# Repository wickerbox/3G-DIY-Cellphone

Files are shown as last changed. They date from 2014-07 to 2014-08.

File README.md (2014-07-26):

cellphone3g
===========

Hardware for a 3G cellphone based on GSM/GPRS Arduino shield and damellis' DIY Cellphone.

[David A Mellis' DIY Cellphone 2G 'Cellphone Module'](http://web.media.mit.edu/~mellis/gsm/)

That project uses the 2G Quectel M10 Module which is pin compatible with the 3G Quectel UC15 Module. 

[Quectel GSM/GPRS M10](http://www.quectel.com/product/prodetail.aspx?id=14)

[Quectel UMTS/HSDPA UC15](http://www.quectel.com/product/prodetail.aspx?id=64)

[Quectel M10 and UC15 Design Compatibility](http://top-electronics.com/news/26/quectel-uc15-and-m10-design-compatibility.html)

**Differences**

1. Slightly different 3.3V-4.3V (UC15) vs 3.3V-4.6V (M10). Using a 3.7V battery is fine. MCP73831 recharges the 3.7V battery from the USB ... if the unit is powered off USB, it's at 4.2V which is on the high end. which is a little too close for comfort so I'd want to replace it with a USIM is the same. 

1. Frequency bands are slightly different but not much.

1. Pinout from controller will have to change. 

**Vocabulary**

GSM - Global System for Mobile Communications, 2G  
GPRS - General Packet Radio Services, packet data service on 2G and 3G  
UMTS - Universal Mobile Telecommunications System, 3G  
HSDPA - High-Speed Downlink Packet Access, allows higher speeds 3G speeds

**Reference**

"GSM (Global System for Mobile Communications, originally Groupe Spécial Mobile), is a standard developed by the European Telecommunications Standards Institute (ETSI) to describe protocols for second generation (2G) digital cellular networks used by mobile phones." [Wikipedia](http://en.wikipedia.org/wiki/GSM)

"General packet radio service (GPRS) is a packet oriented mobile data service on the 2G and 3G cellular communication system's global system for mobile communications (GSM)." [Wikipedia](http://en.wikipedia.org/wiki/General_Packet_Radio_Service)

"UMTS specifies a complete network system, which includes the radio access network (UMTS Terrestrial Radio Access Network, or UTRAN), the core network (Mobile Application Part, or MAP) and the authentication of users via SIM (subscriber identity module) cards." [Wikipedia](http://en.wikipedia.org/wiki/Universal_Mobile_Telecommunications_System)

"High-Speed Downlink Packet Access (HSDPA) is an enhanced 3G (third-generation) mobile-telephony communications protocol in the High-Speed Packet Access (HSPA) family, also dubbed 3.5G, 3G+, or Turbo 3G, which allows networks based on Universal Mobile Telecommunications System (UMTS) to have higher data-transfer speeds and capacity." [Wikipedia](en.wikipedia.org/wiki/High-Speed_Downlink_Packet_Access)

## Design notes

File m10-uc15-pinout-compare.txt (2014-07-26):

PIN   M10           UC15
---   ---           ----
1     SD_DATA       RESERVED
2     SD_CLK        AP_READY
3     SD_CMD        RESERVED
4     RESERVED      RESERVED
5     RESERVED      RESERVED
6     NETLIGHT      NETLIGHT
7     VDD_EXT       VDD_EXT
8     GND           USIM_GND 
9     DBG_RXD       RESERVED
10    DBG_TXD       RESERVED
11    SIM_PRESENCE  USIM_PRESENCE
12    SIM_VDD       USIM_VDD
13    SIM_DATA      USIM_DATA
14    SIM_CLK       USIM_CLK
15    SIM_RST       USIM_RST
16    VRTC          RESERVED
17    EMERG_OFF     RESET_N
18    PWERKEY       PWRKEY
19    AGND          AGND
20    SPK2P         SPK2P
21    SPK1N         SPK1N
22    SPK1P         SPK1P
23    MIC1P         MIC1P
24    MIC1N         MIC1N
25    MIC2P         MIC2P
26    MIC2N         MIC2N
27    RESERVED      RESERVED
28    RESERVED      RESERVED
29    RESERVED      RESERVED
30    RESERVED      RESERVED
31    RESERVED      RESERVED
32    RESERVED      RESERVED
33    RESERVED      RESERVED
34    RESERVED      PCM_DOUT
35    RESERVED      PCM_DIN
36    RESERVED      PCM_CLK
37    RESERVED      PCM_SYNC
38    GPIO1         I2C_SDA
39    RESERVED      I2C_SCL
40    ADC1          ADC1
41    ADC0          ADC0
42    GND           GND
43    RF_ANT        RF_ANT
44    GND           GND
45    GND           GND
46    GND           GND
47    GND           GND
48    GND           GND
49    GND           GND
50    VBAT          VBAT_RF
51    VBAT          VBAT_RF
52    VBAT          VBAT_BB
53    RESERVED      VBAT_BB
54    STATUS        STATUS
55    RI            RI
56    DCD           DCD
57    CTS           CTS
58    RTS           RTS
59    DTR           DTR
60    TXD           TXD
61    RXD           RXD
62    TXD3          USB_DP
63    RXD3          USB_DM
64    GPIO0         USB_VBUS

65                  GND
66                  RESERVED
67                  GND
68                  GND
69-80               RESERVED
81-108              GND

NOTES

1. Keep all RESERVED pins and unused pins unconnected.
2. GND pads 81-108 should be connected to ground. 
3. We need the Telematics version to support the speakers and mic.

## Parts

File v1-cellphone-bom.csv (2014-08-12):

Item | Qty | Refdes | Description | Mfr | Mfr P/N | Digikey P/N | Unit Cost | Total Cost | Notes
1 | 1 | ANT1 | Antenna, Chip, Calvus, 824-960MHZ SMD | Antenova | A10340 | 627-1022-1-ND | $4.78 | $4.78
2 | 11 | C1, C2, C5, C12, C13, C15, C17, C18, C19, C23, C41 | Capacitor, Ceramic, 100nF 16V 5% X7R 0603 | Samsung | CL10B104JO8NNNC | 1276-1061-1-ND | $0.11 | $1.21
3 | 3 | C3, C4, C39 | Capacitor, Ceramic, 4.7uF 16V 10% X7R 0603 | Samsung | CL10A475KO8NNNC | 1276-1784-1-ND | $0.26 | $0.78
4 | 1 | C8 | Capacitor, Ceramic, 3.9pF 100V NP0 0603 | Murata | GQM1885C2A3R9BB01D | 490-4841-1-ND | $0.72 | $0.72
5 | 10 | C6, C7, C9, C24, C27, C28, C29, C33, C34, C35 | Capacitor, Ceramic, 33pF 16V 5% X7R 0603 | AVX | 0603YC330JAT2A | 478-6211-1-ND | $0.12 | $1.20
6 | 1 | C11 | Capacitor, Aluminum, 1000uF 50V 20% Radial | Nichicon | UVR1H102MHD | 493-1111-ND | $0.96 | $0.96
7 | 2 | C10, C14 | Capacitor, Ceramic, 18pF 16V 5% NP0 0603 | Kemet | C0603C180J4GACTU | 399-11141-1-ND | $0.25 | $0.50
8 | 1 | C40 | Capacitor, Ceramic, 10nF 16V 10% X7R 0603 | Samsung | CL10B103KO8NNNC | 1276-1926-1-ND | $0.10 | $0.10
9 | 1 | C26 | Capacitor, Ceramic, 100uF 16V 20% X5R 1210 | Kemet | EMK325ABJ107MM-T | 587-3152-1-ND | $2.30 | $2.30
10 | 8 | C21, C25, C30, C31, C32, C36, C37, C38 | Capacitor, Ceramic, 10pF 50V 5% NP0 0603 | Samsung | CL10C100JB8NCNC | 1276-2154-1-ND | $0.10 | $0.80
11 | 1 | J1 | Connector, AVR ISP, 2x3, Male, R/A, 0.1” | Harwin | M20-8760342 | 952-1922-ND | $0.43 | $0.43
12 | 1 | J2 | Connector, Micro USB-B, SMD with TH Shell | Hirose | ZX62D-B-5P8 | H11610CT-ND | $1.20 | $1.20
13 | 3 | J3,J6,J7 | Connector, Straight, Female, Unshrouded, 4-pin, 0.1” | Sullins | PPPC041LFBN-RC | S7037-ND | $0.60 | $1.80
14 | 1 | J4 | Connector, Straight, Male, Unshrouded, 6-pin, 0.1” | Harwin | M20-9990645 | 952-2269-ND | $0.26 | $0.26
15 | 1 | J5 | Connector, PH Series, Battery, 2-pin, 2MM, SMT | JST | S2B-PH-SM4-TB(LF)(SN) | 455-1749-1-ND | $0.56 | $0.56
16 | 1 | L1 | Inductor, 6.8nH 430mA 0603 | Murata | LQG18HN6N8J00D | 490-1108-1-ND | $0.21 | $0.21
17 | 1 | L2 | Inductor, 3.3nH 500mA 0603 | Murata | LQG18HN3N3S00D | 490-1104-1-ND | $0.21 | $0.21
18 | 5 | LED1, LED2, LED3, LED4, LED5 | LED, Chip, Pure Green, SMD, 0603 | Stanley | BG1111C-TR | 404-1005-1-ND | $0.57 | $2.85
19 | 1 | Q1 | Mic, Electret, Conditioned Analog Omni -44dB | CUI | CMA-4544PF-W | 102-1721-ND | $0.96 | $0.96
20 | 2 | Q2, Q3 | MOSFET, N-CH, 20V 3.2A SOT-23 | ON Semi | NTR4501NT1G | NTR4501NT1GOSCT-ND | $0.59 | $1.18
21 | 3 | R2, R3, R6 | Resistor, 22 OHM 1/4W 5% 0603 | Rohm | ESR03EZPJ220 | RHM22DCT-ND | $0.10 | $0.30
22 | 5 | R1, R5, R7, R9, R10 | Resistor, 470 OHM 1/4W 5% 0603 | Rohm | ESR03EZPJ471 | RHM470DCT-ND | $0.10 | $0.50
23 | 2 | R11, R12 | Resistor, 4.99K 1/8W 1% 0603 | Stackpole | RNCP0603FTD4K99 | RNCP0603FTD4K99CT-ND | $0.05 | $0.10
24 | 1 | R8 | Resistor, 2K 1/8W 1% 0603 | Stackpole | RNCP0603FTD2K00 | RNCP0603FTD2K00CT-ND | $0.05 | $0.05
25 | 1 | R14 | Resistor, 0 OHM 1/8W JUMP 0603 | Vishay | MCT06030Z0000ZP500 | MCT0603-0.0-ZZCT-ND | $0.13 | $0.13
26 | 2 | R4, R13 | Resistor, 10K 1/8W 1% 0603 | Stackpole | RNCP0603FTD10K0 | RNCP0603FTD10K0CT-ND | $0.05 | $0.10
27 | 1 | S1 | Button, Tactile Switch, SPST-NO 0.05A 12V | Omron | B3U-1000P | SW1020CT-ND | $1.25 | $1.25
28 | 1 | SP1 | Speaker, Receiver, 100Hz-9.5kHz 55.5ohm | Knowles | SR6438NWS-000 | 423-1142-ND | $6.27 | $6.27
29 | 1 | U1 | IC, Battery Charge Controller, LiPo, 4.2V, 20T23-5 | Microchip | MCP73831T-2ACI/OT | MCP73831T-2ACI/OTCT-ND | $0.67 | $0.67
30 | 1 | U2 | IC, Microcontroller, 8-bit 128KB FLASH 44TQFP | Atmel | ATMEGA1284P-AUR | ATMEGA1284P-AURCT-ND | $8.99 | $8.99
31 | 1 | U3 | GSM Module, UC15 3G | Quectel | UC15 | SEE NOTE | $65.00 | $65.00 | Order through D'Art Perfect (http://www.d-art-perfect.com/#!product/prd1/1837100545/uc15)
32 | 1 | U4 | IC, Volt Level Translator, 14TSSOP | TI | TXB0104PWR | 296-21929-1-ND | $1.69 | $1.69
33 | 1 | X1 | Connector, SMA Jack, R/A, 50ohm TH | Emerson | 142-0701-301 | J501-ND | $7.76 | $7.76
34 | 1 | X2 | Crystal, 8MHz, 18pF SMD | Abracon | ABM3-8.000MHZ-D2Y-T | 535-10630-1-ND | $1.09 | $1.09
35 | 1 | X3 | Connector, Smart Card (SIM), Hinged, 6-pin SMD | C&K | C707 10M006 5002 | 361-1020-1-ND | $1.03 | $1.03
 |  |  |  |  |  |  | SUM | $117.94 | Total cost with cell module
 |  |  |  |  |  |  | SUM-CELL | $52.94 | Total cost without cell module

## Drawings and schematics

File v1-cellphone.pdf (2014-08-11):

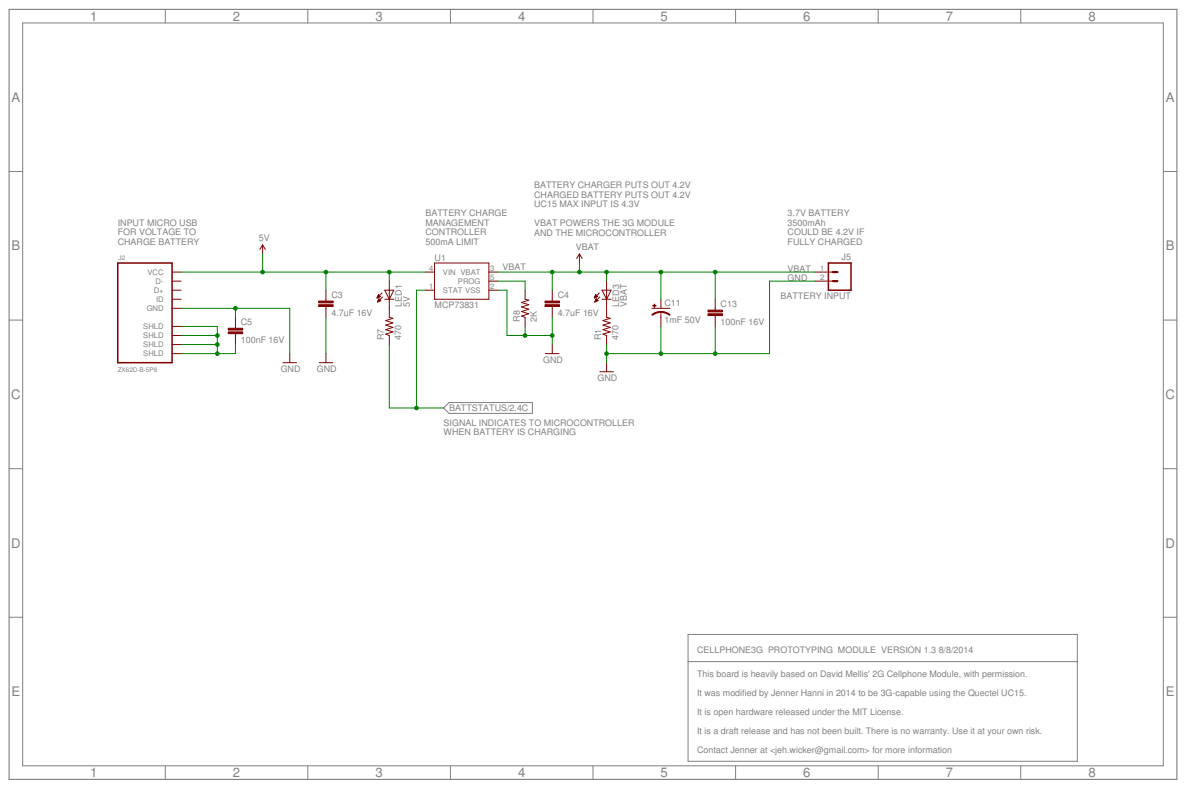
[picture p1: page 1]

BATTERY CHARGER PUTS OUT 4.2V
CHARGED BATTERY PUTS OUT 4.2V
UC15 MAX INPUT IS 4.3V
VBAT POWERS THE 3G MODULE
AND THE MICROCONTROLLER

BATTSTATUS/2.4C
SIGNAL INDICATES TO MICROCONTROLLER
WHEN BATTERY IS CHARGING

This board is heavily based on David Mellis' 2G Cellphone Module, with permission.
It was modified by Jenner Hanni in 2014 to be 3G-capable using the Quectel UC15.
It is open hardware released under the MIT License.
It is a draft release and has not been built. There is no warranty. Use it at your own risk. Contact Jenner at <jeh.wicker@gmail.com> for more information

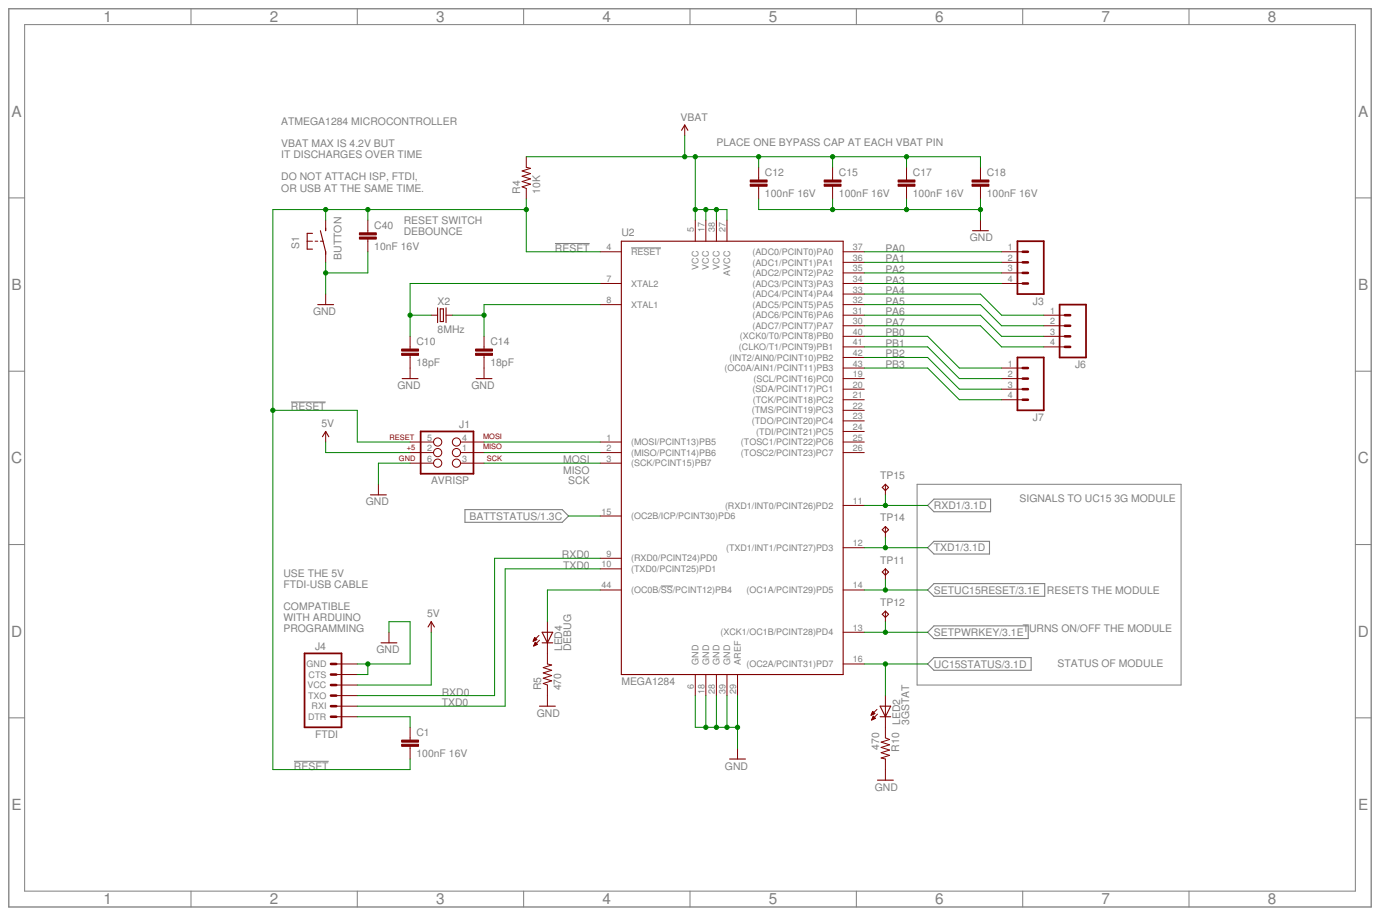
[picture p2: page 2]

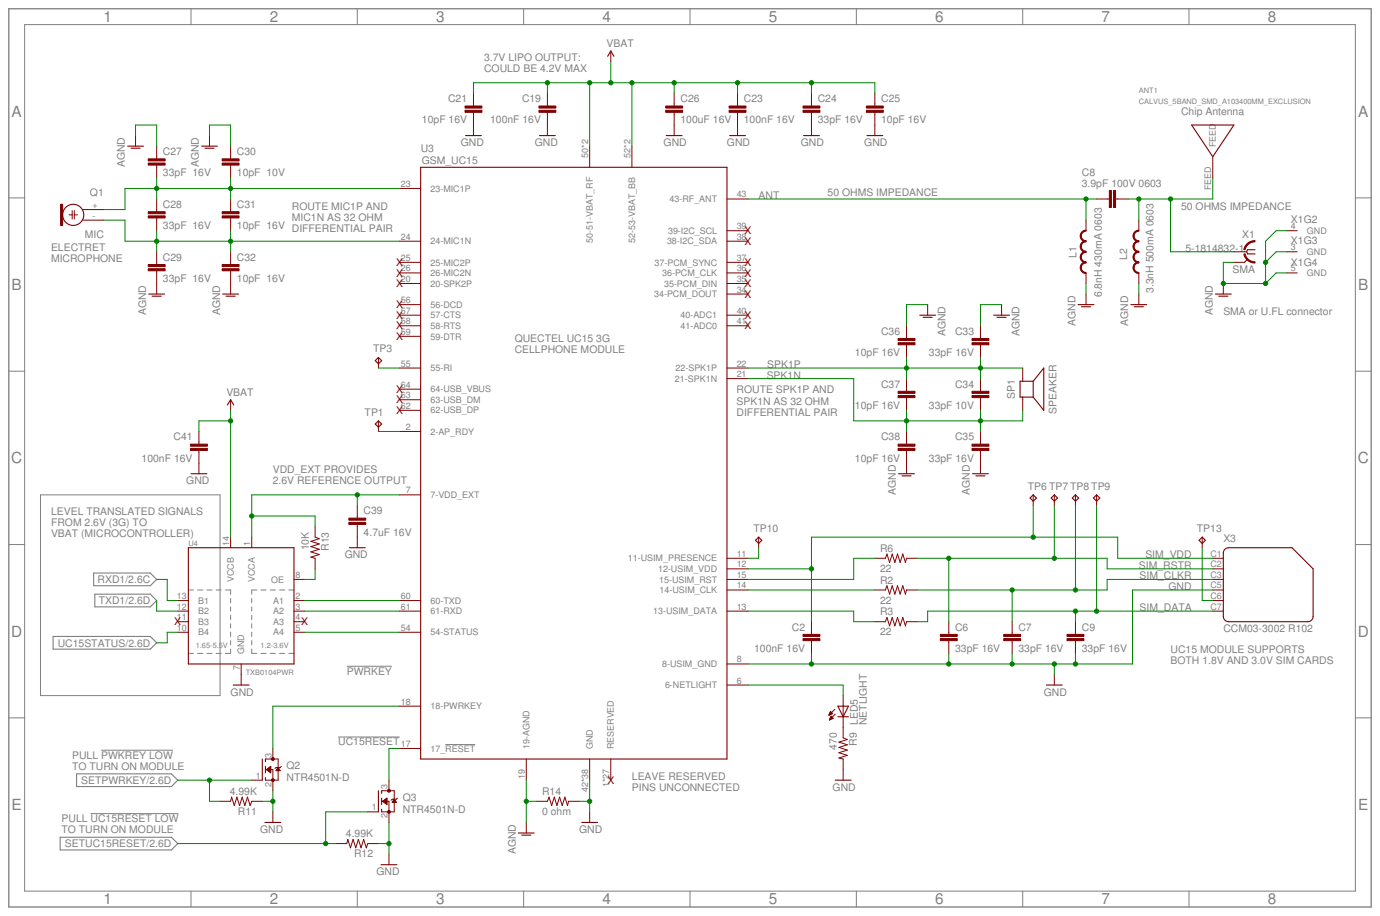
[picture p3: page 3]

VBAT

SMA or U.FL connector

UC15 MODULE SUPPORTS
BOTH 1.8V AND 3.0V SIM CARDS

PULL PWKREY LOW
TO TURN ON MODULE
SETPWRKEY/2.6D

PULL UC15RESET LOW
SETUC15RESET/2.6D

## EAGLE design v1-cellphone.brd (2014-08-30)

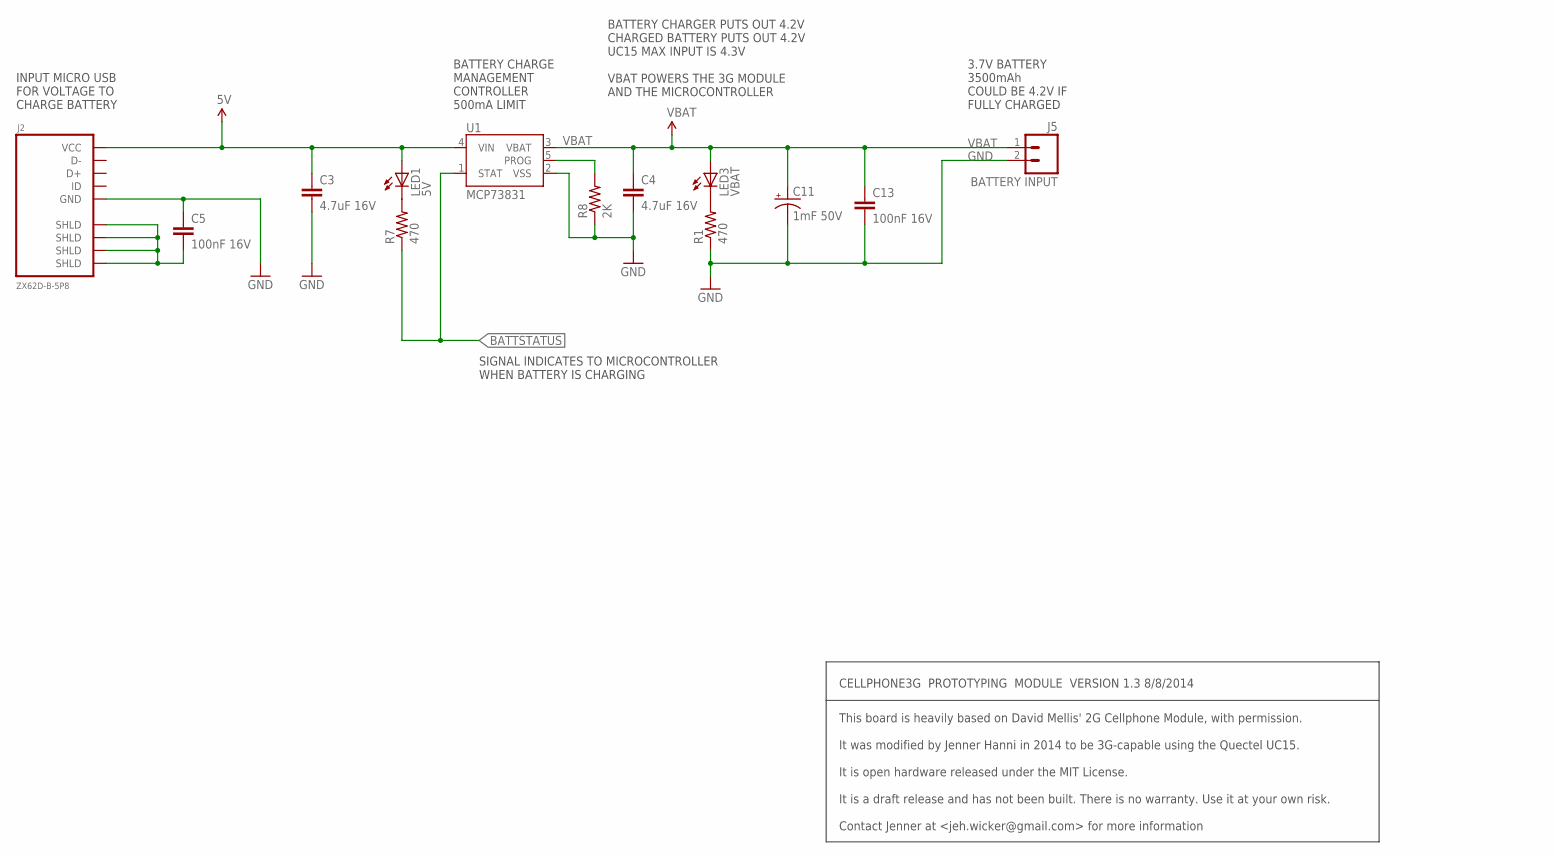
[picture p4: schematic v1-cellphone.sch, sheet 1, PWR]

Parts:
C3, C4: 4.7uF 16V; 0603-B
C5, C13: 100nF 16V; 0603-B
C11: 1mF 50V; CPOL-RADIAL-1000UF-25V
J2: ZX62D-B-5P8
J5: BATTERY INPUT; JST-2-SMD
LED1: 5V; CHIP-LED0603
LED3: VBAT; CHIP-LED0603
R1, R7: 470; 0603-B
R8: 2K; 0603-B
U1: MCP73831; SPARKFUN_SOT23-5

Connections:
5V: C3.1, J2.P1 (VCC), LED1.A, U1.4 (VIN); also elsewhere on the board
BATTSTATUS: R7.1, U1.1 (STAT); also elsewhere on the board
GND: C3.2, C4.2, C5.1, C11.2 (-), C13.2, J2.P5 (GND), J5.2 (1), R1.1, R8.1, U1.2 (VSS); also elsewhere on the board
unnamed: LED3.C, R1.2
unnamed: LED1.C, R7.2
PROG: R8.2, U1.5 (PROG)
SHLD: C5.2, J2.P$1 (SHLD), J2.P$2 (SHLD), J2.P$3 (SHLD), J2.P$4 (SHLD)
VBAT: C4.1, C11.1 (+), C13.1, J5.1 (2), LED3.A, U1.3 (VBAT); also elsewhere on the board

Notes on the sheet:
INPUT MICRO USB FOR VOLTAGE TO CHARGE BATTERY
BATTERY CHARGE MANAGEMENT CONTROLLER 500mA LIMIT
3.7V BATTERY 3500mAh COULD BE 4.2V IF FULLY CHARGED
BATTERY CHARGER PUTS OUT 4.2V CHARGED BATTERY PUTS OUT 4.2V UC15 MAX INPUT IS 4.3V VBAT POWERS THE 3G MODULE AND THE MICROCONTROLLER
CELLPHONE3G PROTOTYPING MODULE VERSION 1.3 8/8/2014
This board is heavily based on David Mellis' 2G Cellphone Module, with permission. It was modified by Jenner Hanni in 2014 to be 3G-capable using the Quectel UC15. It is open hardware released under the MIT License. It is a draft release and has not been built. There is no warranty. Use it at your 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
SIGNAL INDICATES TO MICROCONTROLLER WHEN BATTERY IS CHARGING

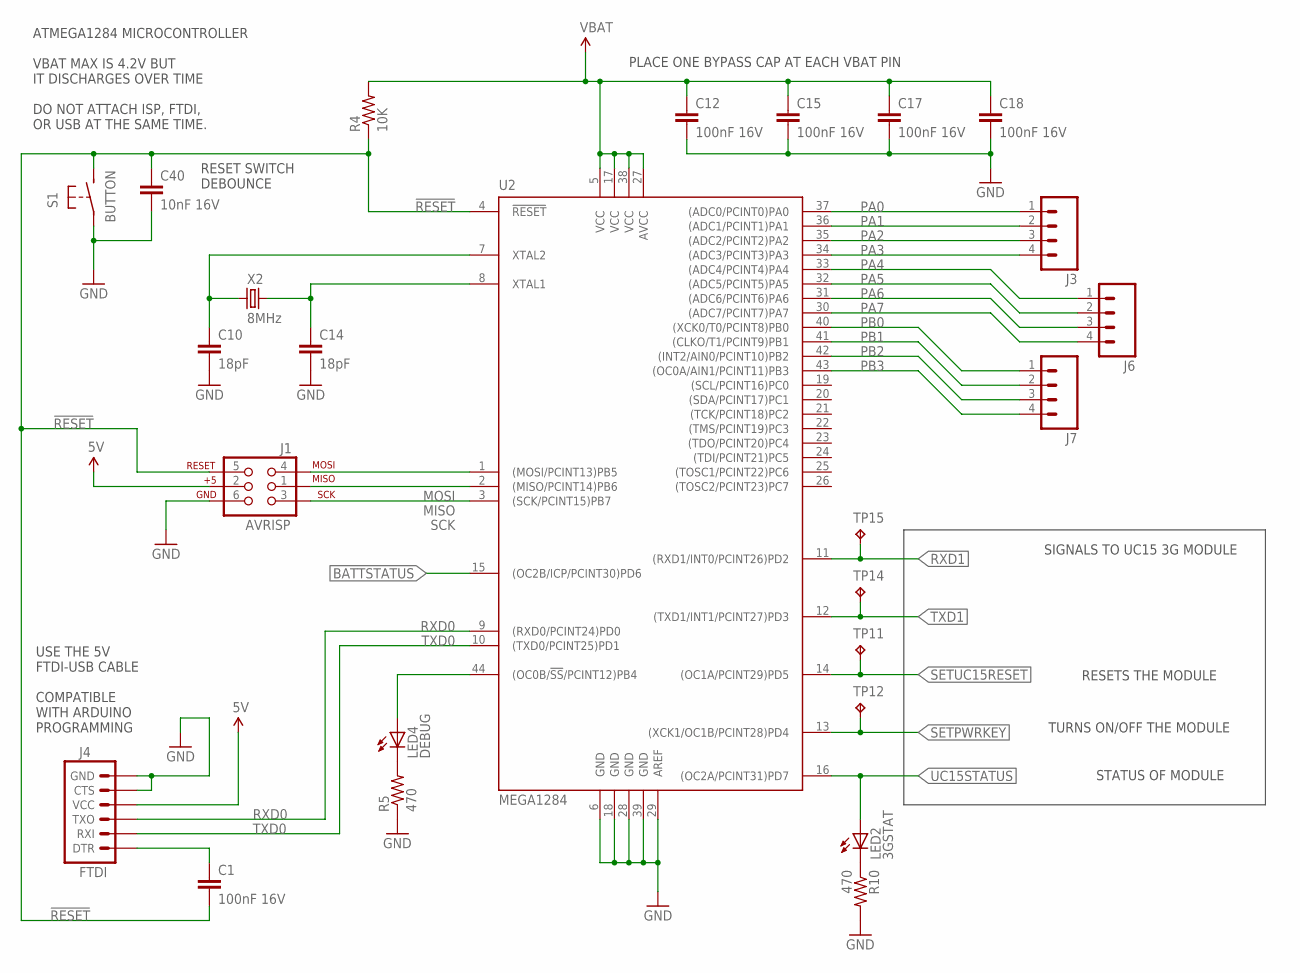
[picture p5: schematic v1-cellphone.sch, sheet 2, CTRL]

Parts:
C1, C12, C15, C17, C18: 100nF 16V; 0603-B
C10, C14: 18pF; 0603-B
C40: 10nF 16V; 0603-B
J1: AVRISP; SPARKFUN-CONNECTORS_2X3-NS
J3, J6, J7: M04LOCK; 1X04_LOCK
J4: FTDI; 1X06_LOCK
LED2: 3GSTAT; CHIP-LED0603
LED4: DEBUG; CHIP-LED0603
R4: 10K; 0603-B
R5, R10: 470; 0603-B
S1: BUTTON; CELLPHONE_B3U-1000P
TP11, TP12, TP14, TP15: TPPAD1-13; P1-13
U2: MEGA1284; AVR-5_TQFP44
X2: 8MHz; 2-SMD-5X3MM

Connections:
5V: J1.2 (2-5VCC), J4.4 (VCC); also elsewhere on the board
!RESET: C1.2, C40.1, J1.5 (5-RESET), R4.1, S1.P$2 (S), U2.4 (!RESET)
BATTSTATUS: U2.15 ((OC2B/ICP/PCINT30)PD6); also elsewhere on the board
DEBUGLED: LED4.A, U2.44 ((OC0B/!SS!/PCINT12)PB4)
GND: C10.2, C12.2, C14.2, C15.2, C17.2, C18.2, C40.2, J1.6 (6-GND), J4.5 (CTS), J4.6 (GND), R5.1, R10.2, S1.P$1, U2.6 (GND), U2.18 (GND), U2.28 (GND), U2.29 (AREF), U2.39 (GND); also elsewhere on the board
MISO: J1.1 (1-MISO), U2.2 ((MISO/PCINT14)PB6)
MOSI: J1.4 (4-MOSI), U2.1 ((MOSI/PCINT13)PB5)
unnamed: LED4.C, R5.2
unnamed: C1.1, J4.1 (DTR)
unnamed: LED2.C, R10.1
PA0: J3.1, U2.37 ((ADC0/PCINT0)PA0)
PA1: J3.2, U2.36 ((ADC1/PCINT1)PA1)
PA2: J3.3, U2.35 ((ADC2/PCINT2)PA2)
PA3: J3.4, U2.34 ((ADC3/PCINT3)PA3)
PA4: J6.1, U2.33 ((ADC4/PCINT4)PA4)
PA5: J6.2, U2.32 ((ADC5/PCINT5)PA5)
PA6: J6.3, U2.31 ((ADC6/PCINT6)PA6)
PA7: J6.4, U2.30 ((ADC7/PCINT7)PA7)
PB0: J7.1, U2.40 ((XCK0/T0/PCINT8)PB0)
PB1: J7.2, U2.41 ((CLKO/T1/PCINT9)PB1)
PB2: J7.3, U2.42 ((INT2/AIN0/PCINT10)PB2)
PB3: J7.4, U2.43 ((OC0A/AIN1/PCINT11)PB3)
RXD0: J4.3 (TXO), U2.9 ((RXD0/PCINT24)PD0)
RXD1: TP15.TP, U2.11 ((RXD1/INT0/PCINT26)PD2); also elsewhere on the board
SCK: J1.3 (3-SCK), U2.3 ((SCK/PCINT15)PB7)
SETPWRKEY: TP12.TP, U2.13 ((XCK1/OC1B/PCINT28)PD4); also elsewhere on the board
SETUC15RESET: TP11.TP, U2.14 ((OC1A/PCINT29)PD5); also elsewhere on the board
TXD0: J4.2 (RXI), U2.10 ((TXD0/PCINT25)PD1)
TXD1: TP14.TP, U2.12 ((TXD1/INT1/PCINT27)PD3); also elsewhere on the board
UC15STATUS: LED2.A, U2.16 ((OC2A/PCINT31)PD7); also elsewhere on the board
VBAT: C12.1, C15.1, C17.1, C18.1, R4.2, U2.5 (VCC), U2.17 (VCC), U2.27 (AVCC), U2.38 (VCC); also elsewhere on the board
XTAL1: C14.1, U2.8 (XTAL1), X2.P$2 (2)
XTAL2: C10.1, U2.7 (XTAL2), X2.P$1 (1)

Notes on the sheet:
PLACE ONE BYPASS CAP AT EACH VBAT PIN
USE THE 5V FTDI-USB CABLE COMPATIBLE WITH ARDUINO PROGRAMMING
TURNS ON/OFF THE MODULE
RESETS THE MODULE
STATUS OF MODULE
SIGNALS TO UC15 3G MODULE
ATMEGA1284 MICROCONTROLLER VBAT MAX IS 4.2V BUT IT DISCHARGES OVER TIME DO NOT ATTACH ISP, FTDI, OR USB AT THE SAME TIME.
RESET SWITCH DEBOUNCE

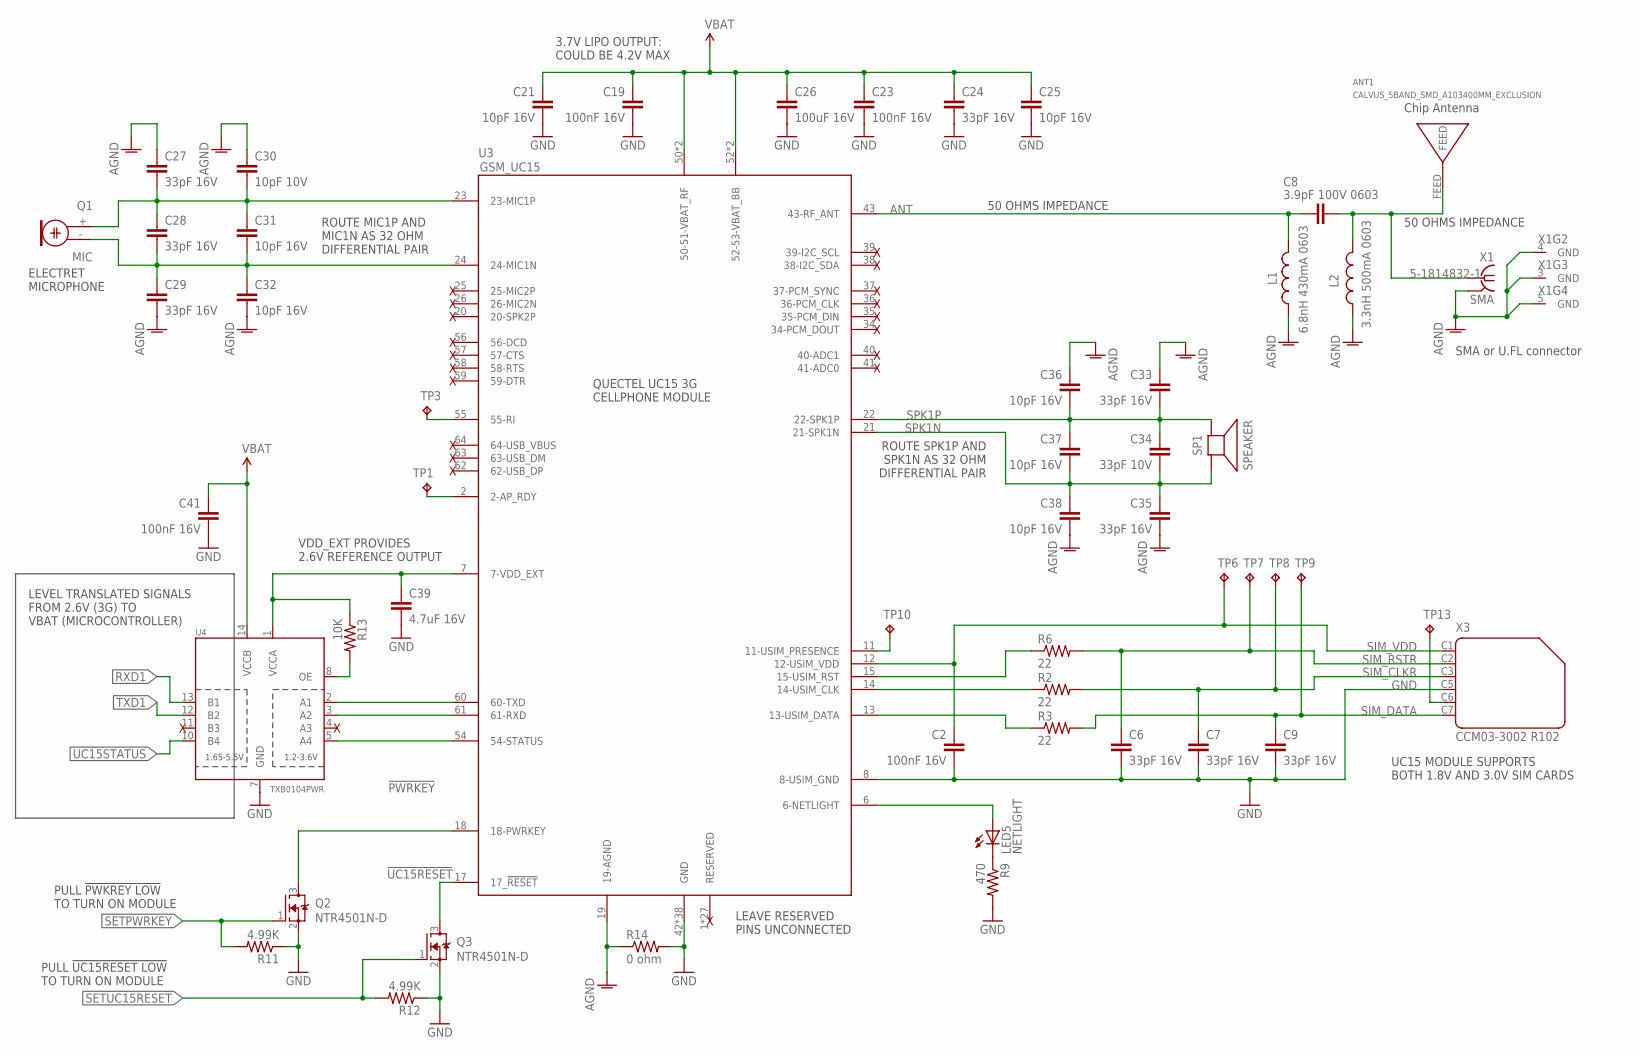
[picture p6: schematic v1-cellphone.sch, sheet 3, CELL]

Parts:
ANT1: CALVUS_5BAND_SMD_A103400MM_EXCLUSION; CALVUS_5BAND_SMD_A10340_0MM_EXCLUSION
C2, C19, C23, C41: 100nF 16V; 0603-B
C6, C7, C9, C24, C27, C28, C29, C33, C35: 33pF 16V; 0603-B
C8: 3.9pF 100V 0603; 0603-B
C21, C25, C31, C32, C36, C37, C38: 10pF 16V; 0603-B
C26: 100uF 16V; C1210K
C30: 10pF 10V; 0603-B
C34: 33pF 10V; 0603-B
C39: 4.7uF 16V; 0603-B
L1: 6.8nH 430mA 0603; 0603-B
L2: 3.3nH 500mA 0603; 0603-B
LED5: NETLIGHT; CHIP-LED0603
Q1: MIC; 9.7ELECTRET
Q2, Q3: NTR4501N-D; SOT-23
R2, R3, R6: 22; 0603-B
R9: 470; 0603-B
R11, R12: 4.99K; 0603-B
R13: 10K; 0603-B
R14: 0 ohm; 0603-B
SP1: SPEAKER; CELLPHONE_SPEAKER-6.4MM
TP1, TP3, TP6, TP7, TP8, TP9, TP10, TP13: TPPAD1-13; P1-13
U3: GSM_UC15; GSM_UC15_WITHOUT_EXCLUSION
U4: TXB0104PWR; TSSOP14
X1: SMA; CON-COAX_BU-SMA-V
X3: CCM03-3002 R102; SMARTPRJ_CON-AMPHENOL_C707_10M006_512_2

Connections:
!PWRKEY: Q2.3 (D), U3.18 (18-PWRKEY)
!UC15RESET: Q3.3 (D), U3.17 (17_!RESET)
AGND: C27.1, C29.2, C30.1, C32.2, C33.1, C35.2, C36.1, C38.2, L1.1, L2.1, R14.1, U3.19 (19-AGND), X1.2 (GND), X1.3 (GND), X1.4 (GND), X1.5 (GND)
ANT: C8.1, L1.2, U3.43 (43-RF_ANT)
ANTENNA: ANT1.FEED, C8.2, L2.2, X1.1
GND: C2.2, C6.2, C7.2, C9.2, C19.2, C21.2, C23.2, C24.2, C25.2, C26.2, C39.2, C41.2, Q2.2 (S), Q3.2 (S), R9.2, R11.1, R12.1, R14.2, U3.8 (8-USIM_GND), U3.42 (GND), U3.44 (GND), U3.45 (GND), U3.46 (GND), U3.47 (GND), U3.48 (GND), U3.49 (GND), U3.65 (GND), U3.67 (GND), U3.68 (GND), U3.81 (GND), U3.82 (GND), U3.83 (GND), U3.84 (GND), U3.85 (GND), U3.86 (GND), U3.87 (GND), U3.88 (GND), U3.89 (GND), U3.90 (GND), U3.91 (GND), U3.92 (GND), U3.93 (GND), U3.94 (GND), U3.95 (GND), U3.96 (GND), U3.97 (GND), U3.98 (GND), U3.99 (GND), U3.100 (GND), U3.101 (GND), U3.102 (GND), U3.103 (GND), U3.104 (GND), U3.105 (GND), U3.106 (GND), U3.107 (GND), U3.108 (GND), U4.7 (GND), X3.C5 (4); also elsewhere on the board
MIC1N: C28.2, C29.1, C31.2, C32.1, Q1.- (1), U3.24 (24-MIC1N)
MIC1P: C27.2, C28.1, C30.2, C31.1, Q1.+ (2), U3.23 (23-MIC1P)
unnamed: R3.1, U3.13 (13-USIM_DATA)
unnamed: LED5.C, R9.1
unnamed: TP13.TP, X3.C6 (5)
unnamed: TP1.TP, U3.2 (2-AP_RDY)
unnamed: TP3.TP, U3.55 (55-RI)
unnamed: U3.60 (60-TXD), U4.2 (A1)
unnamed: U3.61 (61-RXD), U4.3 (A2)
unnamed: U3.54 (54-STATUS), U4.5 (A4)
NETLIGHT: LED5.A, U3.6 (6-NETLIGHT)
OE: R13.2, U4.8 (OE)
PRESENCE: TP10.TP, U3.11 (11-USIM_PRESENCE)
RXD1: U4.13 (B1); also elsewhere on the board
SETPWRKEY: Q2.1 (G), R11.2; also elsewhere on the board
SETUC15RESET: Q3.1 (G), R12.2; also elsewhere on the board
SIM_CLK: R2.1, U3.14 (14-USIM_CLK)
SIM_CLKR: C7.1, R2.2, TP8.TP, X3.C3 (3)
SIM_DATA: C9.1, R3.2, TP9.TP, X3.C7 (6)
SIM_RST: R6.1, U3.15 (15-USIM_RST)
SIM_RSTR: C6.1, R6.2, TP7.TP, X3.C2 (2)
SIM_VDD: C2.1, TP6.TP, U3.12 (12-USIM_VDD), X3.C1 (1)
SPK1N: C34.2, C35.1, C37.2, C38.1, SP1.NEG, U3.21 (21-SPK1N)
SPK1P: C33.2, C34.1, C36.2, C37.1, SP1.POS, U3.22 (22-SPK1P)
TXD1: U4.12 (B2); also elsewhere on the board
UC15STATUS: U4.10 (B4); also elsewhere on the board
VBAT: C19.1, C21.1, C23.1, C24.1, C25.1, C26.1, C41.1, U3.50 (50-51-VBAT_RF), U3.51 (50-51-VBAT_RF), U3.52 (52-53-VBAT_BB), U3.53 (52-53-VBAT_BB), U4.14 (VCCB); also elsewhere on the board
VDD_EXT: C39.1, R13.1, U3.7 (7-VDD_EXT), U4.1 (VCCA)

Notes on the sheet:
Chip Antenna
SMA or U.FL connector
UC15 MODULE SUPPORTS BOTH 1.8V AND 3.0V SIM CARDS
LEAVE RESERVED PINS UNCONNECTED
QUECTEL UC15 3G CELLPHONE MODULE
ELECTRET MICROPHONE
ROUTE MIC1P AND MIC1N AS 32 OHM DIFFERENTIAL PAIR
ROUTE SPK1P AND SPK1N AS 32 OHM DIFFERENTIAL PAIR
50 OHMS IMPEDANCE
3.7V LIPO OUTPUT: COULD BE 4.2V MAX
LEVEL TRANSLATED SIGNALS FROM 2.6V (3G) TO VBAT (MICROCONTROLLER)
PULL !PWKREY LOW TO TURN ON MODULE
PULL !UC15RESET LOW TO TURN ON MODULE
VDD_EXT PROVIDES 2.6V REFERENCE OUTPUT

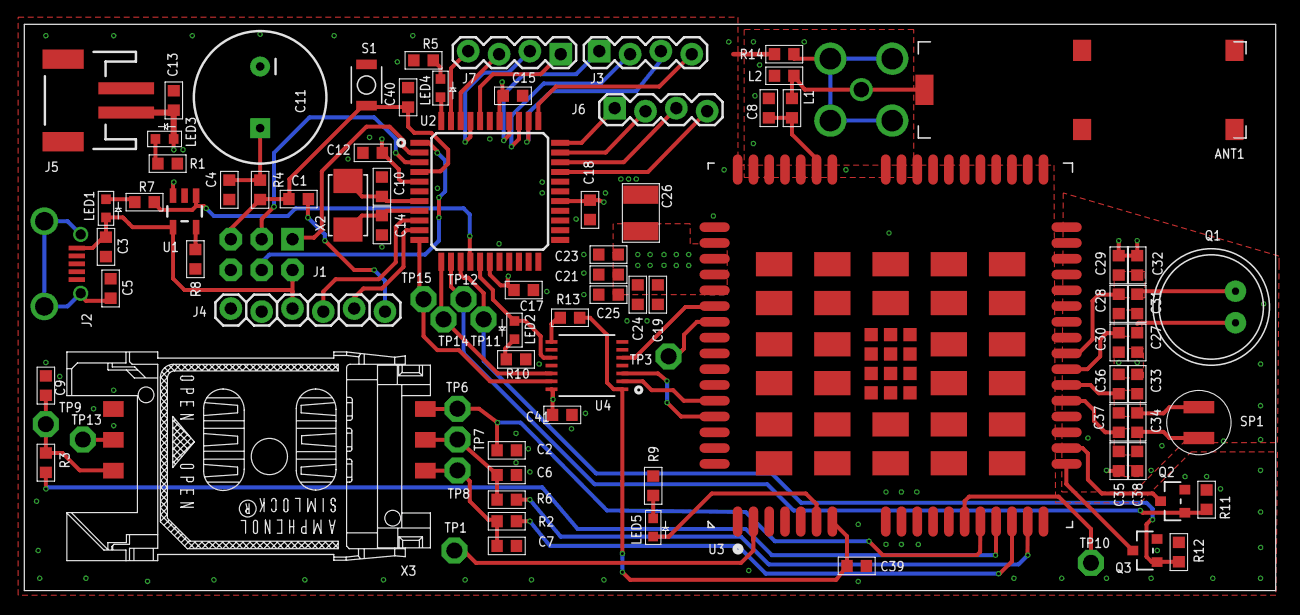
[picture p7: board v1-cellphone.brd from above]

Board: 4 copper layers, 103.1 x 46.7 mm, 91 parts (1 on the bottom side), 64 nets.

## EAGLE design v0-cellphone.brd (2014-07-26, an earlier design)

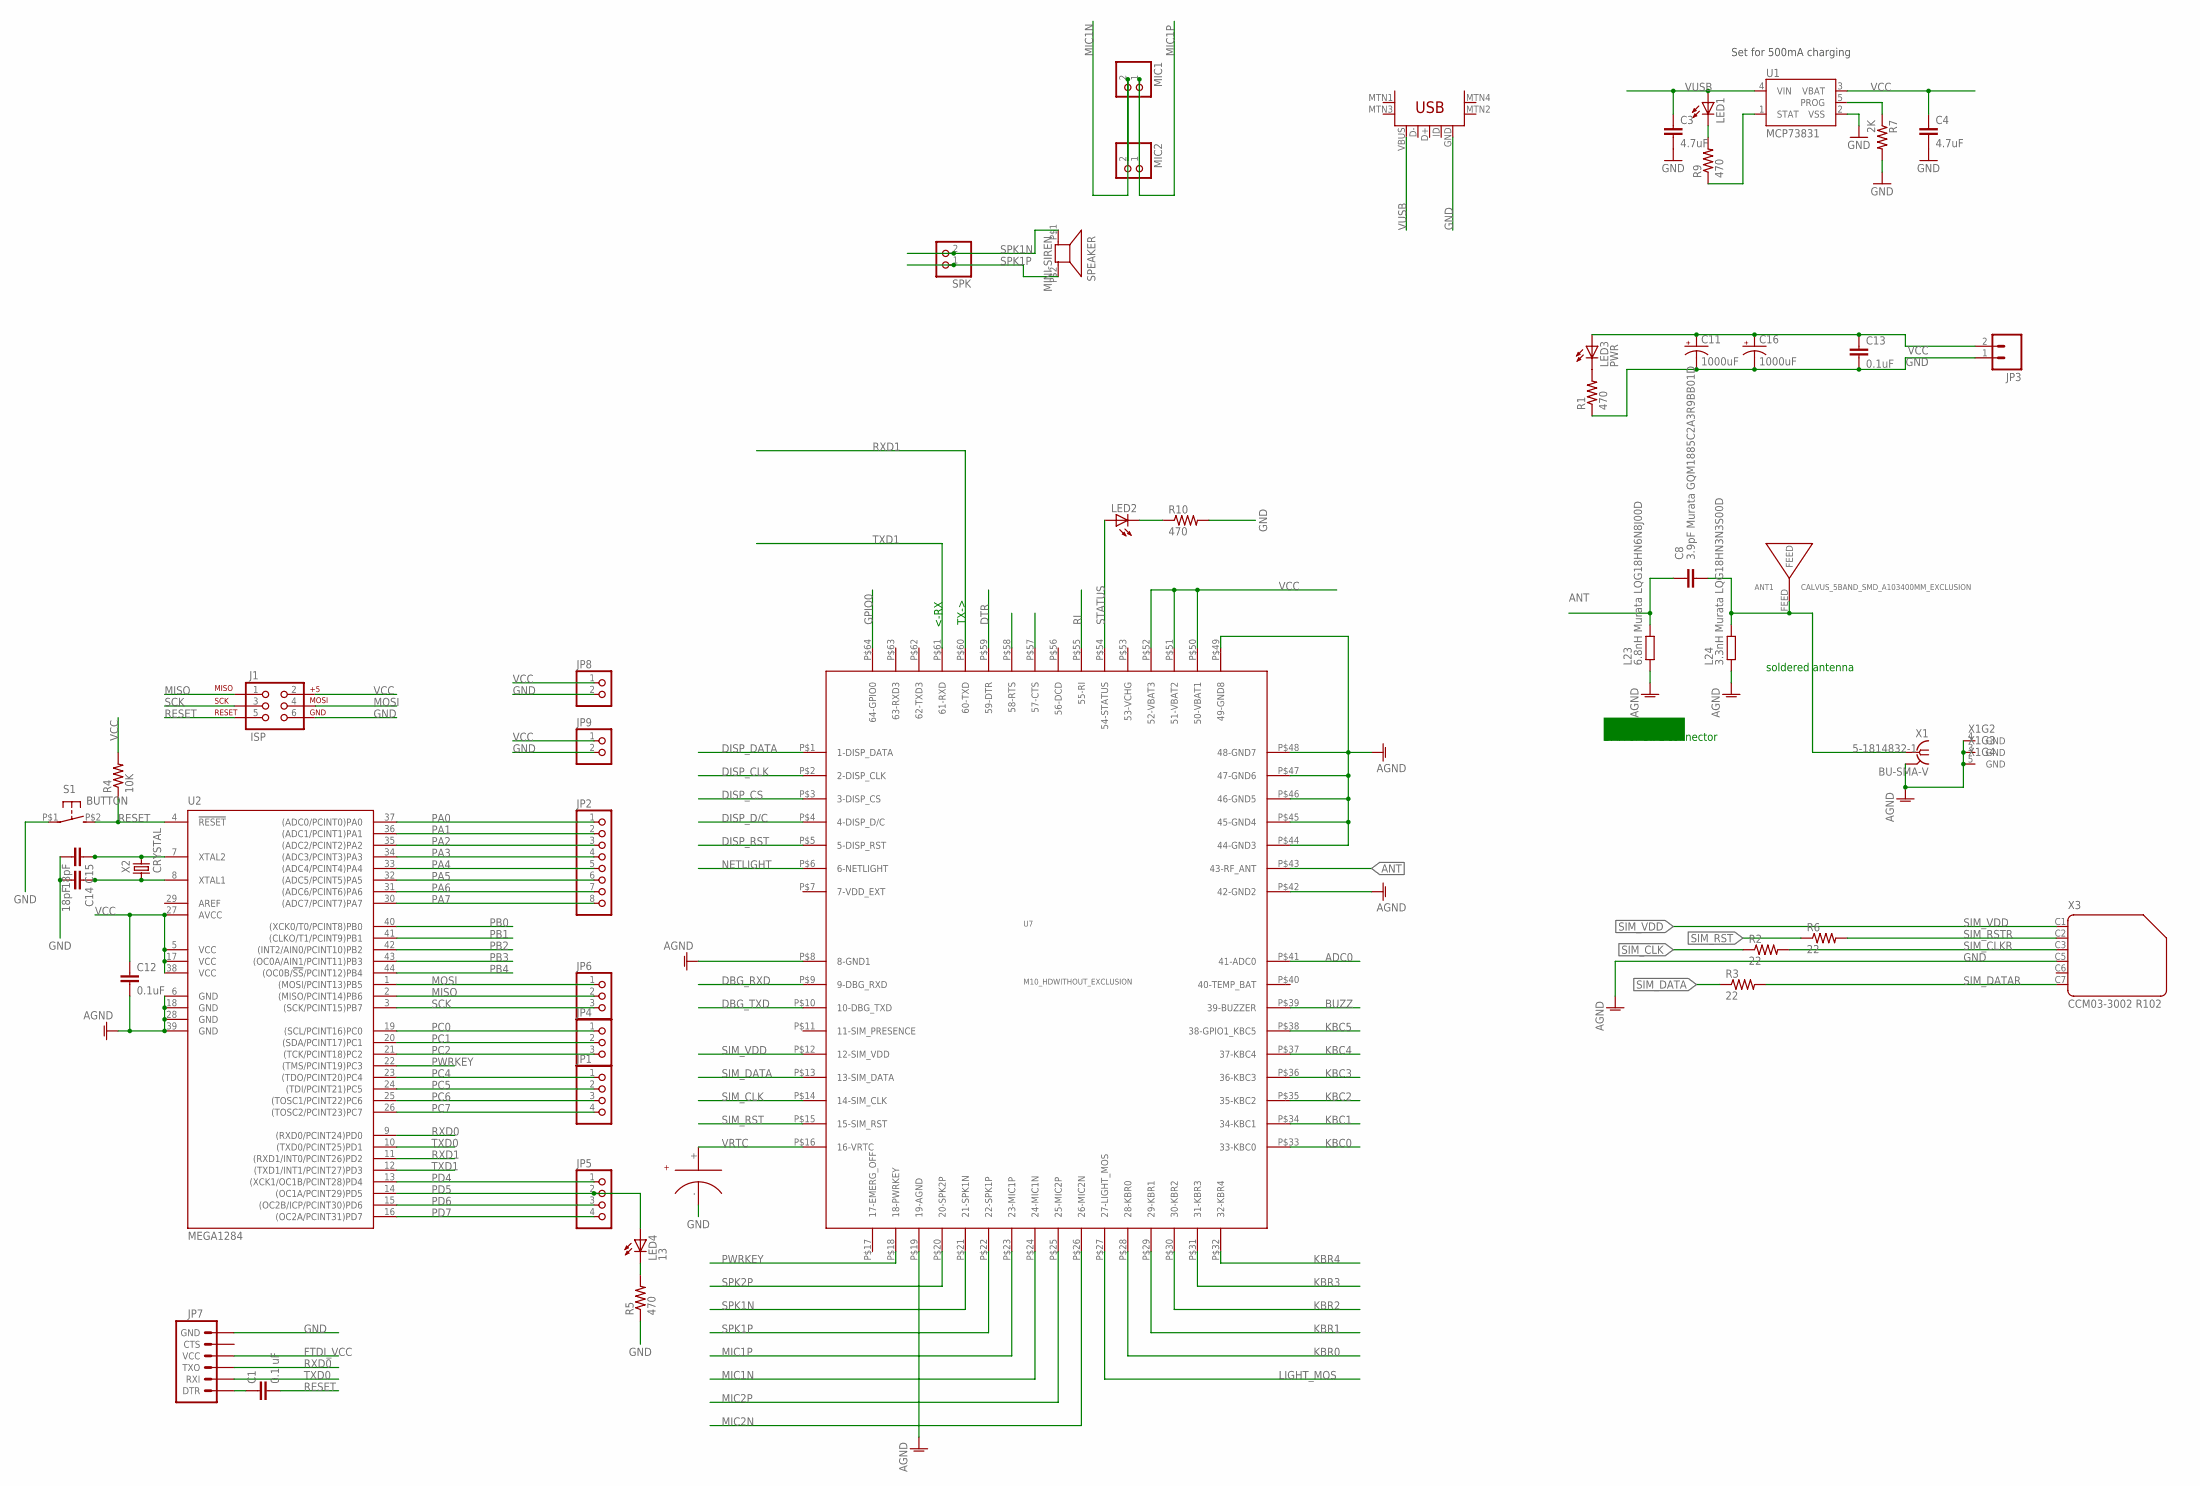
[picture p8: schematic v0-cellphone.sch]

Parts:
ANT1: CALVUS_5BAND_SMD_A103400MM_EXCLUSION; CALVUS_5BAND_SMD_A10340_0MM_EXCLUSION
C1: 0.1 uF; C1206
C2: SUPERCAPPAS; 414-VA5R
C3, C4: 4.7uF; C1206
C8: 3.9pF Murata GQM1885C2A3R9BB01D; C0603-ROUND
C11, C16: 1000uF; D/7343-31R
C12, C13: 0.1uF; C1206
C14, C15: 18pF; C1206
J1: ISP; 2X3-NS
J2: USB-MINIB-5PIN; USB-MINIB
JP1, JP5: PINHD-1X4; 1X04
JP2: PINHD-1X8; 1X08
JP3: M02-JST-2MM-SMT; JST-2-SMD
JP4, JP6: PINHD-1X3; 1X03
JP7: ARDUINO_SERIAL_PROGRAMSMD-NOHOLES; 1X06-SMD-NOHOLES
JP8, JP9: PINHD-1X2; 1X02
L23: 6.8nH Murata LQG18HN6N8J00D; R0603-ROUND
L24: 3.3nH Murata LQG18HN3N3S00D; R0603-ROUND
LED1, LED2: LEDSMT1206; 1206
LED3: PWR; 1206
LED4: 13; 1206
MIC1, MIC2: PINHD-1X2; 1X02
R1, R5, R9, R10: 470; R1206
R2, R3, R6: 22; R1206
R4: 10K; R1206
R7: 2K; R1206
S1: BUTTON; B3U-1000P
SPEAKER: MINI-SIREN; SPEAKER-6.4MM
SPK: PINHD-1X2; 1X02
U1: MCP73831; SOT23-5
U2: MEGA1284; TQFP44
U7: M10_HDWITHOUT_EXCLUSION; M10_HD_WITHOUT_EXCLUSION
X1: BU-SMA-V
X2: CRYSTAL; 2-SMD-5X3MM
X3: CCM03-3002 R102; CON-AMPHENOL_C707_10M006_512_2

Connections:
ADC0: U7.P$41 (41-ADC0)
ANT: C8.1, L23.2, U7.P$43 (43-RF_ANT)
ANTENA: ANT1.FEED, C8.2, L24.2, X1.1
AREF: U2.29 (AREF)
BUZZ: U7.P$39 (39-BUZZER)
DBG_RXD: U7.P$9 (9-DBG_RXD)
DBG_TXD: U7.P$10 (10-DBG_TXD)
DISP_CLK: U7.P$2 (2-DISP_CLK)
DISP_CS: U7.P$3 (3-DISP_CS)
DISP_D/C: U7.P$4 (4-DISP_D/C)
DISP_DATA: U7.P$1 (1-DISP_DATA)
DISP_RST: U7.P$5 (5-DISP_RST)
DTR: U7.P$59 (59-DTR)
FTDI_VCC: JP7.4 (VCC)
GND: C2.-, C3.2, C4.2, C11.-, C12.2, C13.2, C14.2, C15.2, C16.-, J1.6, J2.GND, JP3.1 (2), JP7.6 (GND), JP8.2, JP9.2, L23.1, L24.1, R1.1, R5.1, R7.2, R10.2, S1.P$1, U1.2 (VSS), U2.6 (GND), U2.18 (GND), U2.28 (GND), U2.39 (GND), U7.P$8 (8-GND1), U7.P$19 (19-AGND), U7.P$42 (42-GND2), U7.P$44 (44-GND3), U7.P$45 (45-GND4), U7.P$46 (46-GND5), U7.P$47 (47-GND6), U7.P$48 (48-GND7), U7.P$49 (49-GND8), X1.2 (GND), X1.3 (GND), X1.4 (GND), X1.5 (GND), X3.C5 (4)
GPIO0: U7.P$64 (64-GPIO0)
KBC0: U7.P$33 (33-KBC0)
KBC1: U7.P$34 (34-KBC1)
KBC2: U7.P$35 (35-KBC2)
KBC3: U7.P$36 (36-KBC3)
KBC4: U7.P$37 (37-KBC4)
KBC5: U7.P$38 (38-GPIO1_KBC5)
KBR0: U7.P$28 (28-KBR0)
KBR1: U7.P$29 (29-KBR1)
KBR2: U7.P$30 (30-KBR2)
KBR3: U7.P$31 (31-KBR3)
KBR4: U7.P$32 (32-KBR4)
LIGHT_MOS: U7.P$27 (27-LIGHT_MOS)
MIC1N: MIC1.2, MIC2.2, U7.P$24 (24-MIC1N)
MIC1P: MIC1.1, MIC2.1, U7.P$23 (23-MIC1P)
MIC2N: U7.P$26 (26-MIC2N)
MIC2P: U7.P$25 (25-MIC2P)
MISO: J1.1, JP6.2, U2.2 ((MISO/PCINT14)PB6)
MOSI: J1.4, JP6.1, U2.1 ((MOSI/PCINT13)PB5)
unnamed: LED3.C, R1.2
unnamed: LED4.C, R5.2
unnamed: C1.1, JP7.1 (DTR)
unnamed: C15.1, U2.7 (XTAL2), X2.P$2 (2)
unnamed: C14.1, U2.8 (XTAL1), X2.P$1 (1)
unnamed: R9.1, U1.1 (STAT)
unnamed: LED1.C, R9.2
unnamed: LED2.C, R10.1
NETLIGHT: U7.P$6 (6-NETLIGHT)
PA0: JP2.1, U2.37 ((ADC0/PCINT0)PA0)
PA1: JP2.2, U2.36 ((ADC1/PCINT1)PA1)
PA2: JP2.3, U2.35 ((ADC2/PCINT2)PA2)
PA3: JP2.4, U2.34 ((ADC3/PCINT3)PA3)
PA4: JP2.5, U2.33 ((ADC4/PCINT4)PA4)
PA5: JP2.6, U2.32 ((ADC5/PCINT5)PA5)
PA6: JP2.7, U2.31 ((ADC6/PCINT6)PA6)
PA7: JP2.8, U2.30 ((ADC7/PCINT7)PA7)
PB0: U2.40 ((XCK0/T0/PCINT8)PB0)
PB1: U2.41 ((CLKO/T1/PCINT9)PB1)
PB2: U2.42 ((INT2/AIN0/PCINT10)PB2)
PB3: U2.43 ((OC0A/AIN1/PCINT11)PB3)
PB4: U2.44 ((OC0B/!SS!/PCINT12)PB4)
PC0: JP4.1, U2.19 ((SCL/PCINT16)PC0)
PC1: JP4.2, U2.20 ((SDA/PCINT17)PC1)
PC2: JP4.3, U2.21 ((TCK/PCINT18)PC2)
PC4: JP1.1, U2.23 ((TDO/PCINT20)PC4)
PC5: JP1.2, U2.24 ((TDI/PCINT21)PC5)
PC6: JP1.3, U2.25 ((TOSC1/PCINT22)PC6)
PC7: JP1.4, U2.26 ((TOSC2/PCINT23)PC7)
PD4: JP5.1, U2.13 ((XCK1/OC1B/PCINT28)PD4)
PD5: JP5.2, LED4.A, U2.14 ((OC1A/PCINT29)PD5)
PD6: JP5.3, U2.15 ((OC2B/ICP/PCINT30)PD6)
PD7: JP5.4, U2.16 ((OC2A/PCINT31)PD7)
PROG: R7.1, U1.5 (PROG)
PWRKEY: U2.22 ((TMS/PCINT19)PC3), U7.P$18 (18-PWRKEY)
RESET: C1.2, J1.5, R4.1, S1.P$2 (S), U2.4 (!RESET)
RI: U7.P$55 (55-RI)
RXD0: JP7.3 (TXO), U2.9 ((RXD0/PCINT24)PD0)
RXD1: U2.11 ((RXD1/INT0/PCINT26)PD2), U7.P$60 (60-TXD)
SCK: J1.3, JP6.3, U2.3 ((SCK/PCINT15)PB7)
SIM_CLK: R2.1, U7.P$14 (14-SIM_CLK)
SIM_CLKR: R2.2, X3.C3 (3)
SIM_DATA: R3.1, U7.P$13 (13-SIM_DATA)
SIM_DATAR: R3.2, X3.C7 (6)
SIM_RST: R6.1, U7.P$15 (15-SIM_RST)
SIM_RSTR: R6.2, X3.C2 (2)
SIM_VDD: U7.P$12 (12-SIM_VDD), X3.C1 (1)
SPK1N: SPEAKER.P$1 (1), SPK.2, U7.P$21 (21-SPK1N)
SPK1P: SPEAKER.P$2 (2), SPK.1, U7.P$22 (22-SPK1P)
SPK2P: U7.P$20 (20-SPK2P)
STATUS: LED2.A, U7.P$54 (54-STATUS)
TXD0: JP7.2 (RXI), U2.10 ((TXD0/PCINT25)PD1)
TXD1: U2.12 ((TXD1/INT1/PCINT27)PD3), U7.P$61 (61-RXD)
VCC: C4.1, C11.+, C12.1, C13.1, C16.+, J1.2, JP3.2 (1), JP8.1, JP9.1, LED3.A, R4.2, U1.3 (VBAT), U2.5 (VCC), U2.17 (VCC), U2.27 (AVCC), U2.38 (VCC), U7.P$50 (50-VBAT1), U7.P$51 (51-VBAT2), U7.P$52 (52-VBAT3)
VRTC: C2.+, U7.P$16 (16-VRTC)
VUSB: C3.1, J2.VBUS, LED1.A, U1.4 (VIN)

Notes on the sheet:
soldered antenna
SMA or U.FL connector
TX->
<-RX
Set for 500mA charging

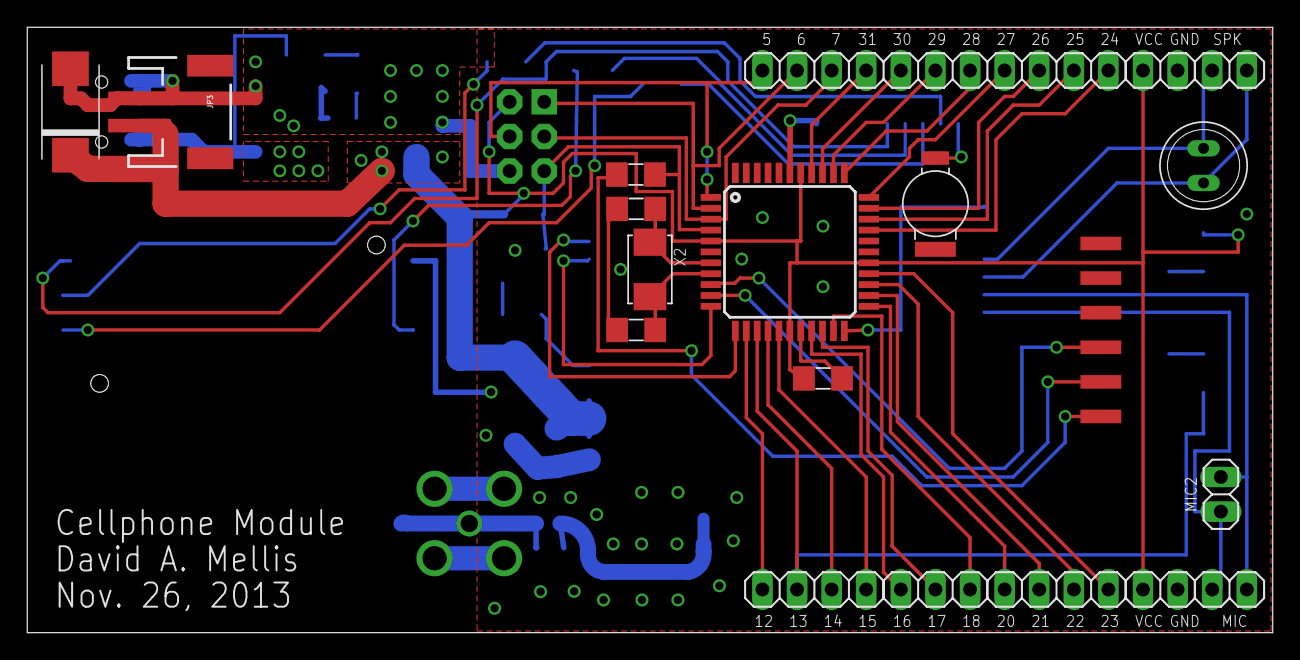
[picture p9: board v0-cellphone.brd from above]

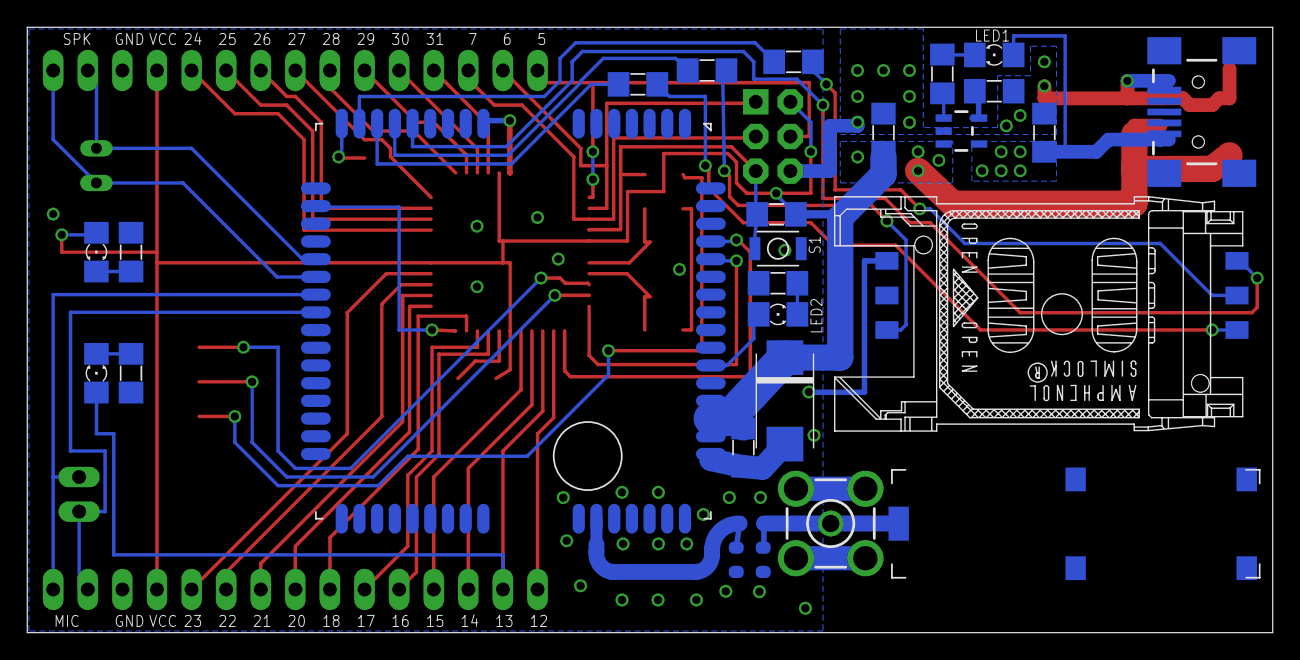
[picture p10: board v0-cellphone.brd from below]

Board: 2 copper layers, 91.4 x 44.5 mm, 49 parts (28 on the bottom side), 55 nets.

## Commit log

2014-07-26 Added reference eagle schematic from damellis' cellphone2hw
    [v0-cellphone.brd, v0-cellphone.sch]
2014-07-26 Did a first pass through all parts of circuit. Annotated schematic. Made changes to library.
    [v1-cellphone.brd, v1-cellphone.sch]
2014-08-02 Ready for review at diy devices.
    [v1-cellphone.brd, v1-cellphone.sch]
2014-08-02 Added notes.
    [v1-cellphone.brd, v1-cellphone.sch]
2014-08-03 Version 1.2 with diode and power changes, package fixes to 0603.
    [v1-cellphone.brd, v1-cellphone.sch]
2014-08-08 Major power changes. Fixed 2.6V signal lines. Ready for review.
    [v1-cellphone.brd, v1-cellphone.sch]
2014-08-08 Added caps, made frames same size.
    [v1-cellphone.brd, v1-cellphone.sch]
2014-08-09 Made proper BOM of new board.
    [v1-cellphone-bom.csv]
2014-08-09 Verified packages. Minor tweaks throughout.
    [v1-cellphone-bom.csv, v1-cellphone.brd, v1-cellphone.sch]
2014-08-09 All tracks routed. Needs review and impedance checks.
    [v1-cellphone-bom.csv, v1-cellphone.brd, v1-cellphone.sch]
2014-08-10 Fixed UC15 package. Passes ERC, DRC. Cleaned silk.
    [v1-cellphone.brd, v1-cellphone.sch]
2014-08-11 Final for release. Passes ERC, DRC.
    [v1-cellphone-bom.csv, v1-cellphone.brd, v1-cellphone.sch]
2014-08-11 Fixed format problem.
    [v1-cellphone-bom.csv]
2014-08-12 Trying to fix TSV error
    [v1-cellphone-bom.csv]
2014-08-12 Nope, that didn't work.
    [v1-cellphone-bom.csv]
2014-08-12 Better formatting on the TSV file?
    [v1-cellphone-bom.tsv]
2014-08-12 CSV fails because it ought to be TSV.
    [v1-cellphone-bom.tsv]
2014-08-30 Fixed switched R2 and C7 silkscreen labels.
    [v1-cellphone.brd, v1-cellphone.sch]

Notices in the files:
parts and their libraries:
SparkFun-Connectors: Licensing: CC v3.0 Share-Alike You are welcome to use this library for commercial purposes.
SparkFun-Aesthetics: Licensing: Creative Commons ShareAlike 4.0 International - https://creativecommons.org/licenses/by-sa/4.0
